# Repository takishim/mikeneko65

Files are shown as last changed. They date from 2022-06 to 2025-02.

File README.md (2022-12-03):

# Mikeneko65
(日本語版は[こちら](./README_jp.md))

A simple 65% keyboard for DIYers. This project was forked from [kkatano's Bakeneko65](https://github.com/kkatano/bakeneko-65).

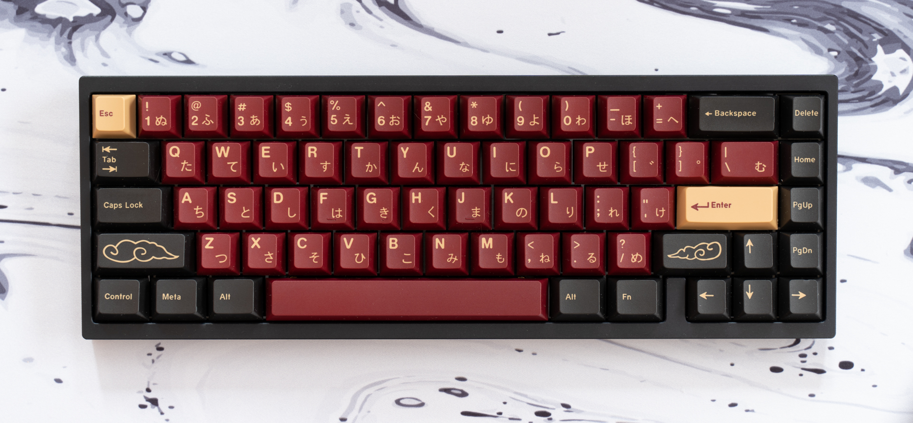
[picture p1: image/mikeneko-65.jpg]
Mikeneko65


-  [【極上の打鍵感】Mikeneko65 レビュー | Mikeneko65 : Custom Mechanical Keyboard Review](https://www.youtube.com/watch?v=eKG2YrfDjyA)

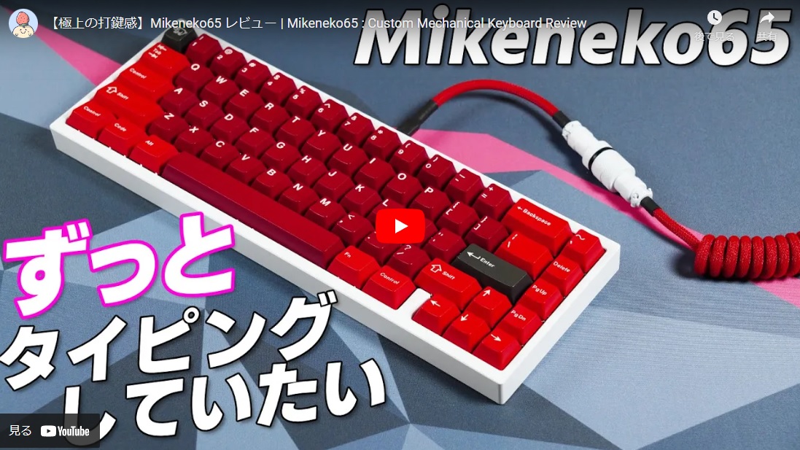
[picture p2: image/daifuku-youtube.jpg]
【極上の打鍵感】Mikeneko65 レビュー | Mikeneko65 : Custom Mechanical Keyboard Review (https://www.youtube.com/watch?v=eKG2YrfDjyA)


## Updates

### Differences between Bakeneko65 V3 and Mikeneko65

- Changed switch type from soldering to hotswap socket
- Supported for PCB screw-ins stabilizer
- Changed MCU to ATmega32U4-MU(R) to deal with MCU supply shortage
- Added pcb/case/sockeet/switch foam

## Features

- Single piece tray case
- O-ring gasket mount (Friction fit)
- Uses [Unified Daughterboard](https://github.com/ai03-2725/Unified-Daughterboard) and [Simplified Daughterboard](https://github.com/kb-elmo/simplified-daughterboard) as daughterboard
- Supports QMK firmware, VIA, Remap and Vial
- PCB designed with KiCAD 5.1.12

## Layout

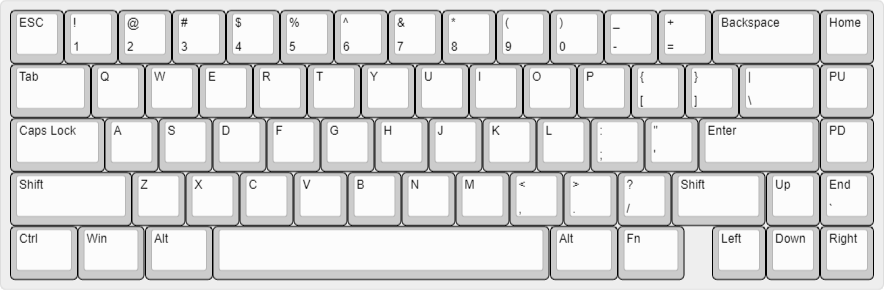
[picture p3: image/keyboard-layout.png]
Mikeneko65 layouts


## Buide guide

[Build Guide(English)](https://github.com/takishim/mikeneko65-docs/blob/master/BUILDGUIDE_en.md)

## Specs

- Dimensions: 315 x 110 x 30mm
- Front height: 18.5mm
- Home row height: 31mm(with GMK keycaps and bumpons)
- Typing angle: 6 degree
- Weight: 760g
- O-ring gasket: VMQ-30A AS568-263(softer) or VMQ-50A AS568-264(harder) is recommended

## Notes

- All files are to be used at your own risk

## Firmware & JSON definition file
- [Firmware(VIA Supported)](./mikeneko65_via.hex)
- [Firmware(VIA NOT Supported)](./mikeneko65_default.hex)
- [QMK Source Code](https://github.com/qmk/qmk_firmware/tree/master/keyboards/mikeneko65)
- [VIA Source Code](https://github.com/the-via/keyboards/tree/master/src/mikeneko65)
- [JSON file for VIA/Remap/Vial](./mikeneko65_via.json))
- [JOSN file for KeyboardLayoutEditor](./mikeneko65_kle.json))

You can download firmware and JSON files by right-clicking on the link and selecting "Save link as".  
These firmwares are built with QMK 0.17.9.

## Community

- Discord: [takishim's server](https://discord.gg/w4NRNrZkBp)
  - Have fun with community members
  - Talk about Mikeneko65 builds and mods, and share your works
  - You can also contact me from there

Please do not ask questions about Mikeneko65 on kkatano's discord server as it will be an inconvenience.

## Special thanks to

- **kkatano** Open-sourced Bakeneko65 and answered my questions in his community
- **desuchan** Allowed me to use the plate he designed
- People who supported the development of Mikeneko65

## Also I should mention
- Many keyboard community members for giving me advice and feedback, really thanks!

## Kit
Available at [Takishim Studio](https://takishim.com/).

## Photo Gallery
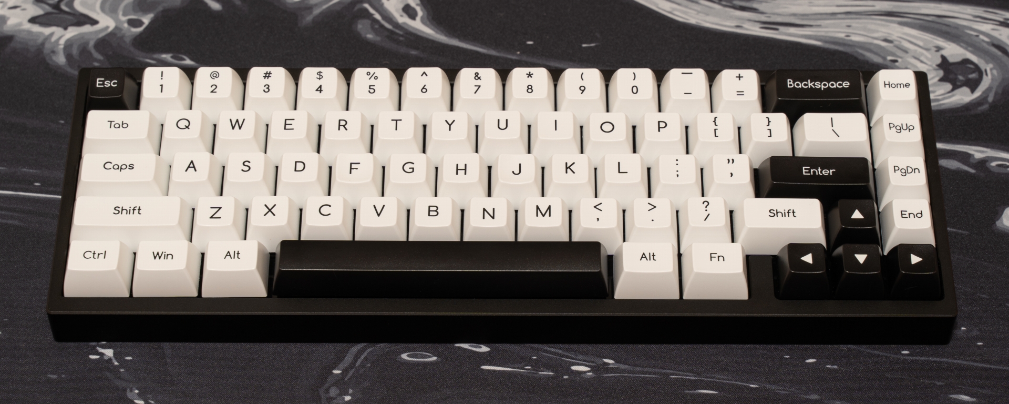
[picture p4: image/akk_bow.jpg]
akk_bow

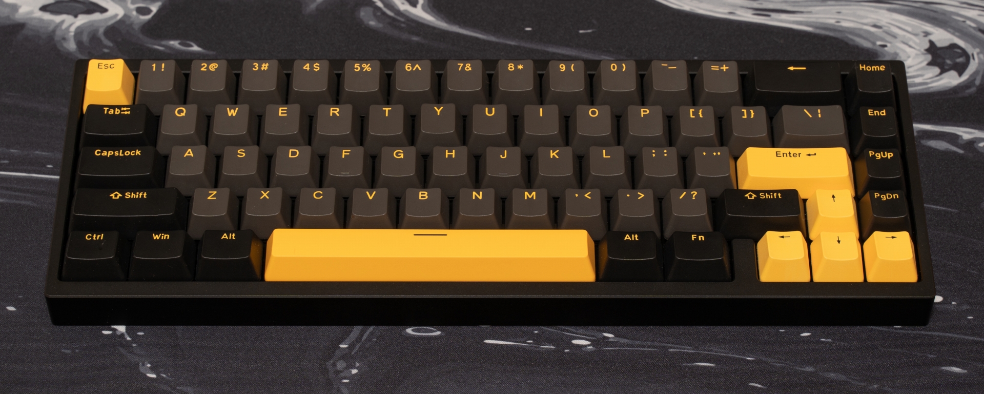
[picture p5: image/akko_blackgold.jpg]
akko_blackgold

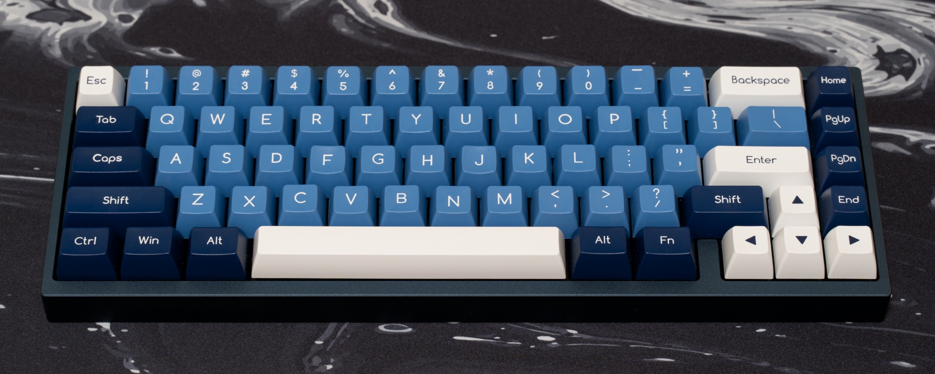
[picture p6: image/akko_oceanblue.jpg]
akko_oceanblue

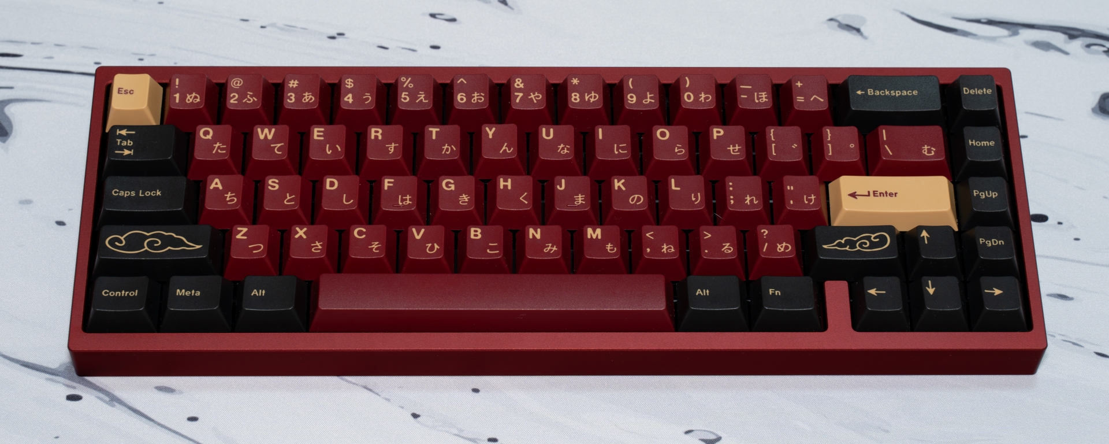
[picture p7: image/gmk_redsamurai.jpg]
gmk_redsamurai

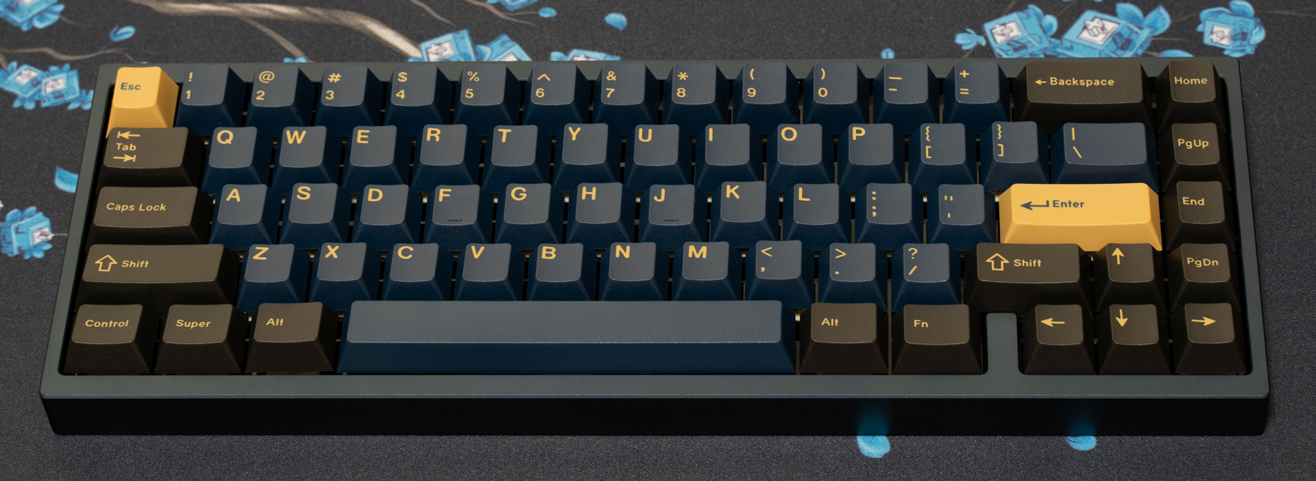
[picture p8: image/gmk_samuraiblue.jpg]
gmk_samuraiblue

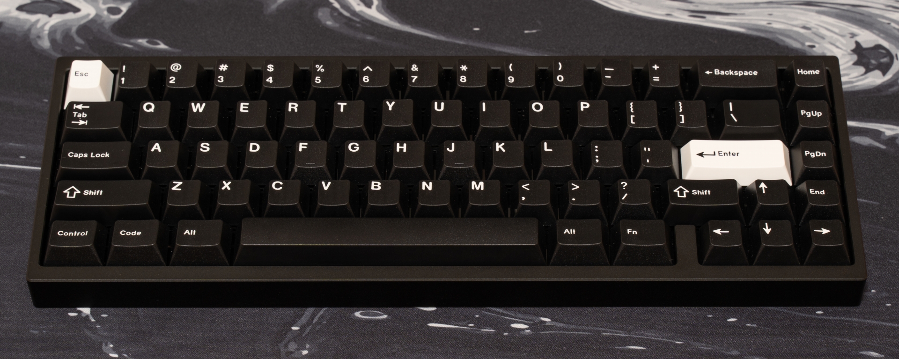
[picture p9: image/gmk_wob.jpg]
gmk_wob

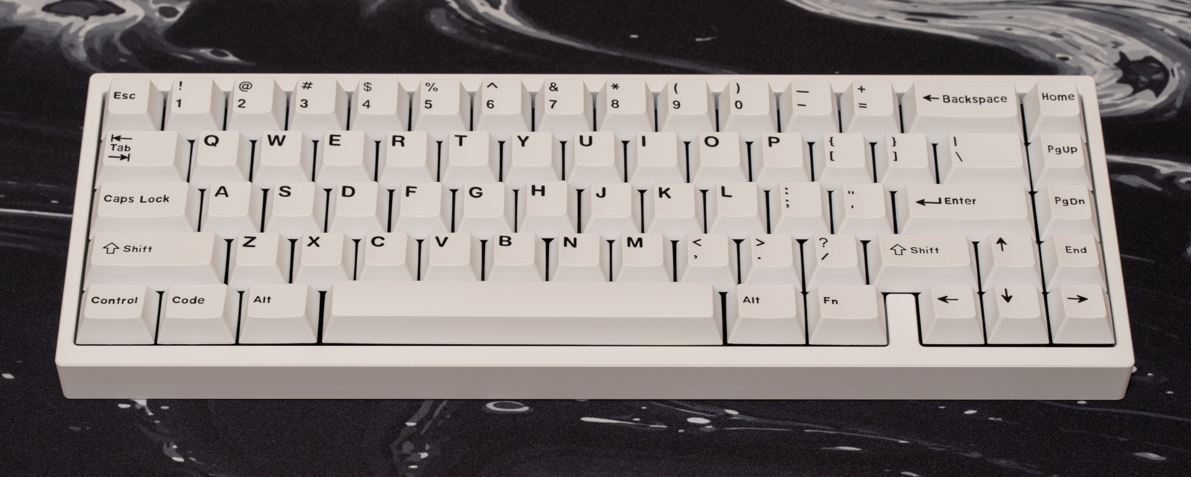
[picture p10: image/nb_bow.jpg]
nb_bow

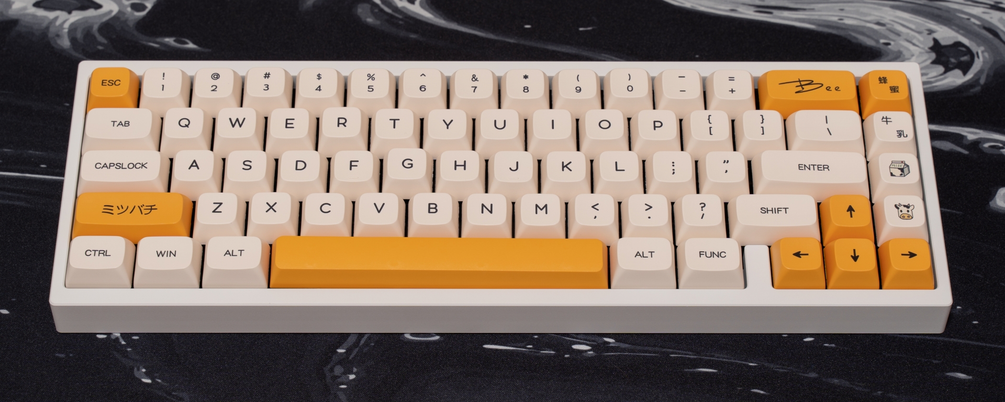
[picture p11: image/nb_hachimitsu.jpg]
nb_hachimitsu

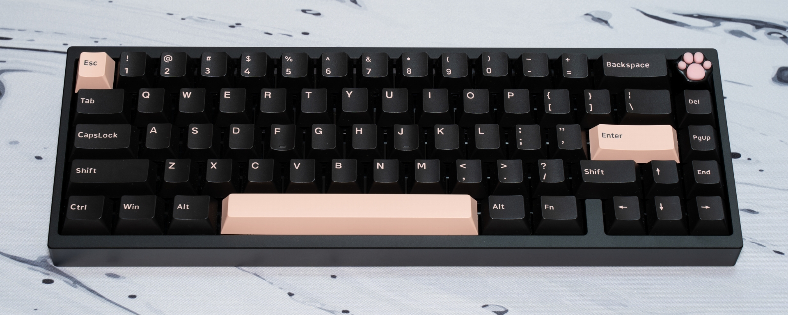
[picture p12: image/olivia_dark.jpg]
olivia_dark

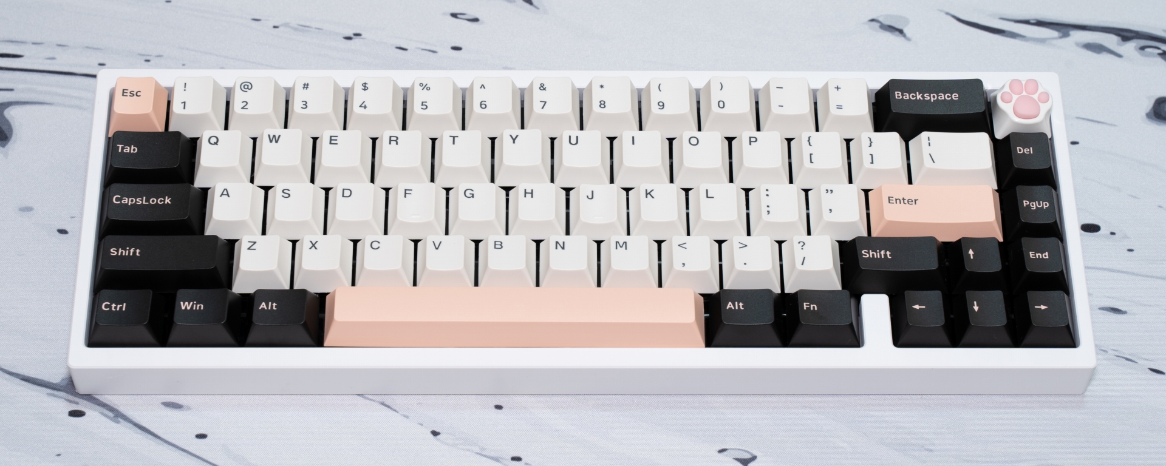
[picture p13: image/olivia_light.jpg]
olivia_light

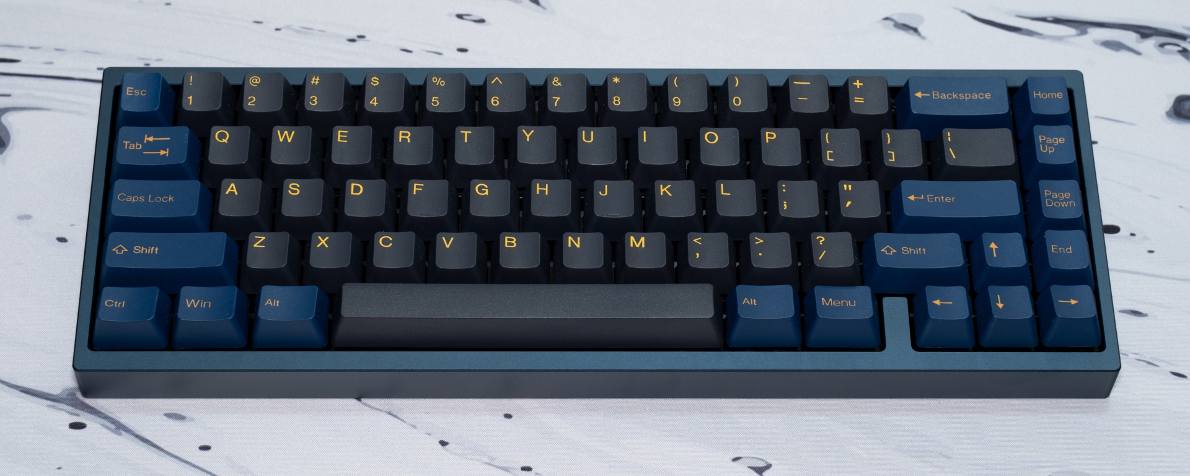
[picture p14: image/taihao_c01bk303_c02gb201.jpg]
taihao_c01bk303_c02gb201


## Reveiw Movies
[4K Mikeneko65](https://www.youtube.com/watch?v=AP2OyEw8YFc) by KS Japan

[Mikeneko65 with Gateron Oil King [Sound Test]](https://www.youtube.com/watch?v=dd4mWbpZy44) by Keyboard Test

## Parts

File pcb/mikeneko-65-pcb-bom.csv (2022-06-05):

Designator | Comment | Footprint | LCSC Part #
C1 C2 C3 | 0.1u | Capacitor_SMD:C_0805_2012Metric | C49678
C4 | 10u | Capacitor_SMD:C_0805_2012Metric | C15850
C5 C6 | 22p | Capacitor_SMD:C_0805_2012Metric | C1804
C7 | 1u | Capacitor_SMD:C_0805_2012Metric | C28323
D1 D2 D3 D4 D5 D6 D7 D8 D9 D10 D11 D12 D13 D14 D15 D16 D17 D18 D19 D20 D21 D22 D23 D24 D25 D26 D27 D28 D29 D30 D31 D32 D33 D34 D35 D36 D37 D38 D39 D40 D41 D42 D43 D44 D45 D46 D47 D48 D49 D50 D51 D52 D53 D54 D55 D56 D57 D58 D59 D60 D61 D62 D63 D64 D65 D66 D67 | 1N4148 | Diode_SMD:D_SOD-123 | C81598
F1 | 500mA | Fuse:Fuse_1206_3216Metric | C70076
J1 | JST SH 4-pin | Connector_JST:JST_SH_SM04B-SRSS-TB_1x04-1MP_P1.00mm_Horizontal | C145956
MX1 MX2 MX3 MX4 MX5 MX6 MX7 MX8 MX9 MX10 MX11 MX12 MX13 MX15 MX17 MX18 MX19 MX20 MX21 MX22 MX23 MX24 MX25 MX26 MX27 MX28 MX30 MX32 MX33 MX34 MX35 MX36 MX37 MX38 MX39 MX40 MX41 MX42 MX44 MX46 MX47 MX48 MX49 MX50 MX51 MX52 MX53 MX54 MX55 MX57 MX58 MX65 MX66 MX67 | 1u | MX_Only:MXOnly-1U-Hotswap | C2803348
MX14 | 2u | MX_Only:MXOnly-2U-Hotswap | C2803348
MX16 MX29 | 1.5u | MX_Only:MXOnly-1.5U-Hotswap | C2803348
MX31 MX56 | 1.75u | MX_Only:MXOnly-1.75U-Hotswap | C2803348
MX43 MX45 | 2.25u | MX_Only:MXOnly-2.25U-Hotswap | C2803348
MX59 MX60 MX61 MX63 MX64 | 1.25u | MX_Only:MXOnly-1.25U-Hotswap | C2803348
MX62 | 6.25u | MX_Only:MXOnly-6.25U-Hotswap-ReversedStabilizers | C2803348
R1 R4 | 10k | Resistor_SMD:R_0805_2012Metric | C17414
R2 R3 | 22 | Resistor_SMD:R_0805_2012Metric | C17561
SW1 | Reset | Button_Switch_SMD:SW_SPST_TL3342 | C318884
U1 | SRV05-4 | Package_TO_SOT_SMD:SOT-23-6 | C85364
U2 | ATmega32U4-MUR | Package_DFN_QFN:QFN-44-1EP_7x7mm_P0.5mm_EP5.2x5.2mm | C45874
Y1 | 16MHz | Crystal:Crystal_SMD_3225-4Pin_3.2x2.5mm | C13738

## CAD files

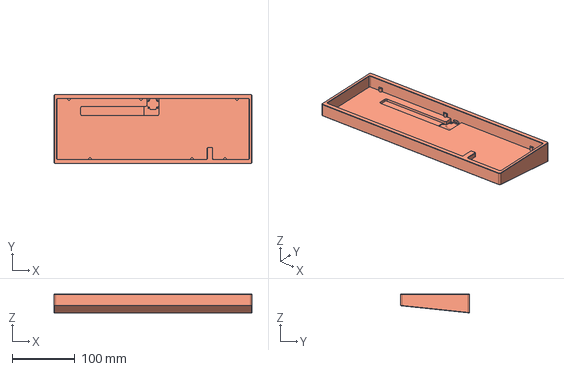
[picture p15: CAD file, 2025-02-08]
case/mikeneko65-simple-case.step
314.8 x 110.2 x 30.0 mm

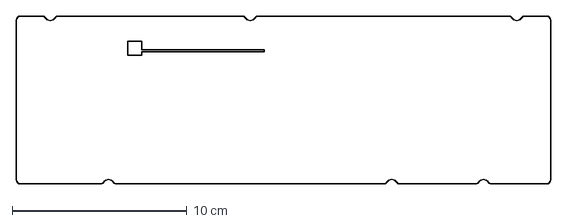
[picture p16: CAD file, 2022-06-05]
foam/mikeneko-65-case-foam.dxf
30.5 x 9.58 cm

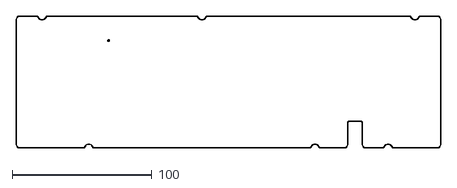
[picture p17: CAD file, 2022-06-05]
pcb/pcb-outline.dxf
303.8 x 94.2

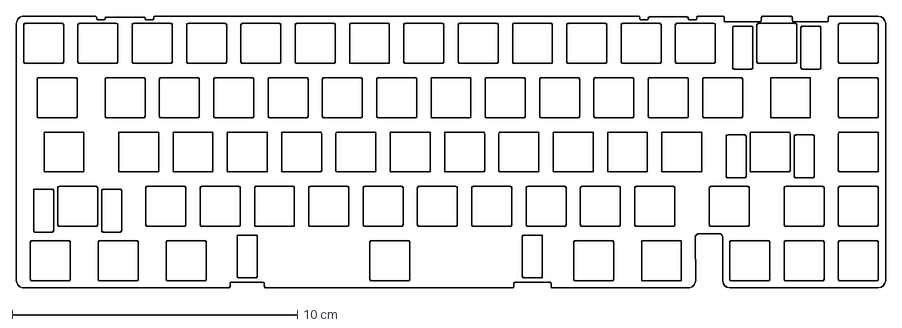
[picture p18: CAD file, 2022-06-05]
plate/mikeneko-65-plate.dxf
30.5 x 9.53 cm

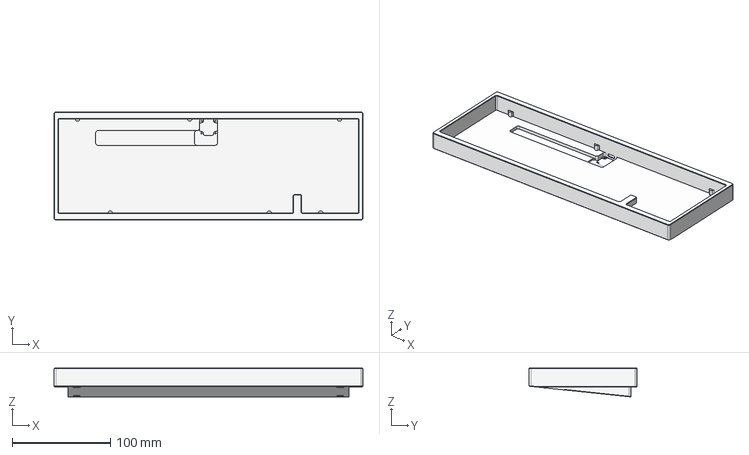
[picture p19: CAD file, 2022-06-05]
case/mikeneko-65-case.step
314.8 x 110.2 x 29.4 mm

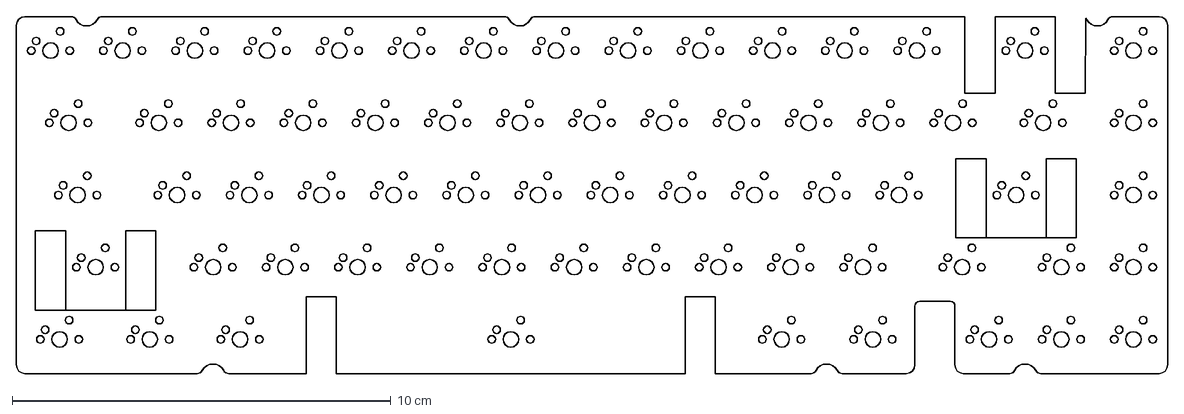
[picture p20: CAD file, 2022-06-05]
foam/mikeneko-65-switch-foam.dxf
30.4 x 9.42 cm

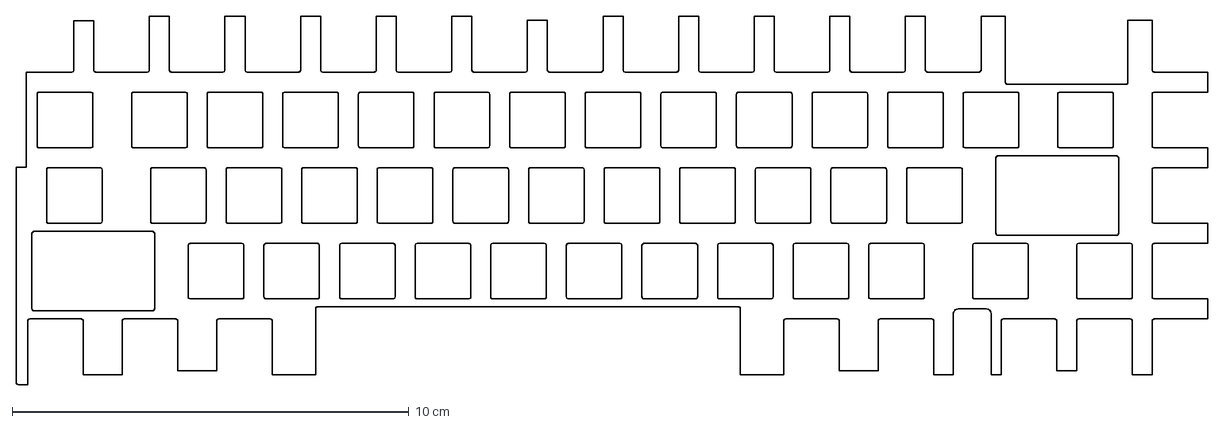
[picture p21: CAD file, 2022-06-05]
foam/mikeneko-65-pcb-foam.dxf
30.0 x 9.27 cm

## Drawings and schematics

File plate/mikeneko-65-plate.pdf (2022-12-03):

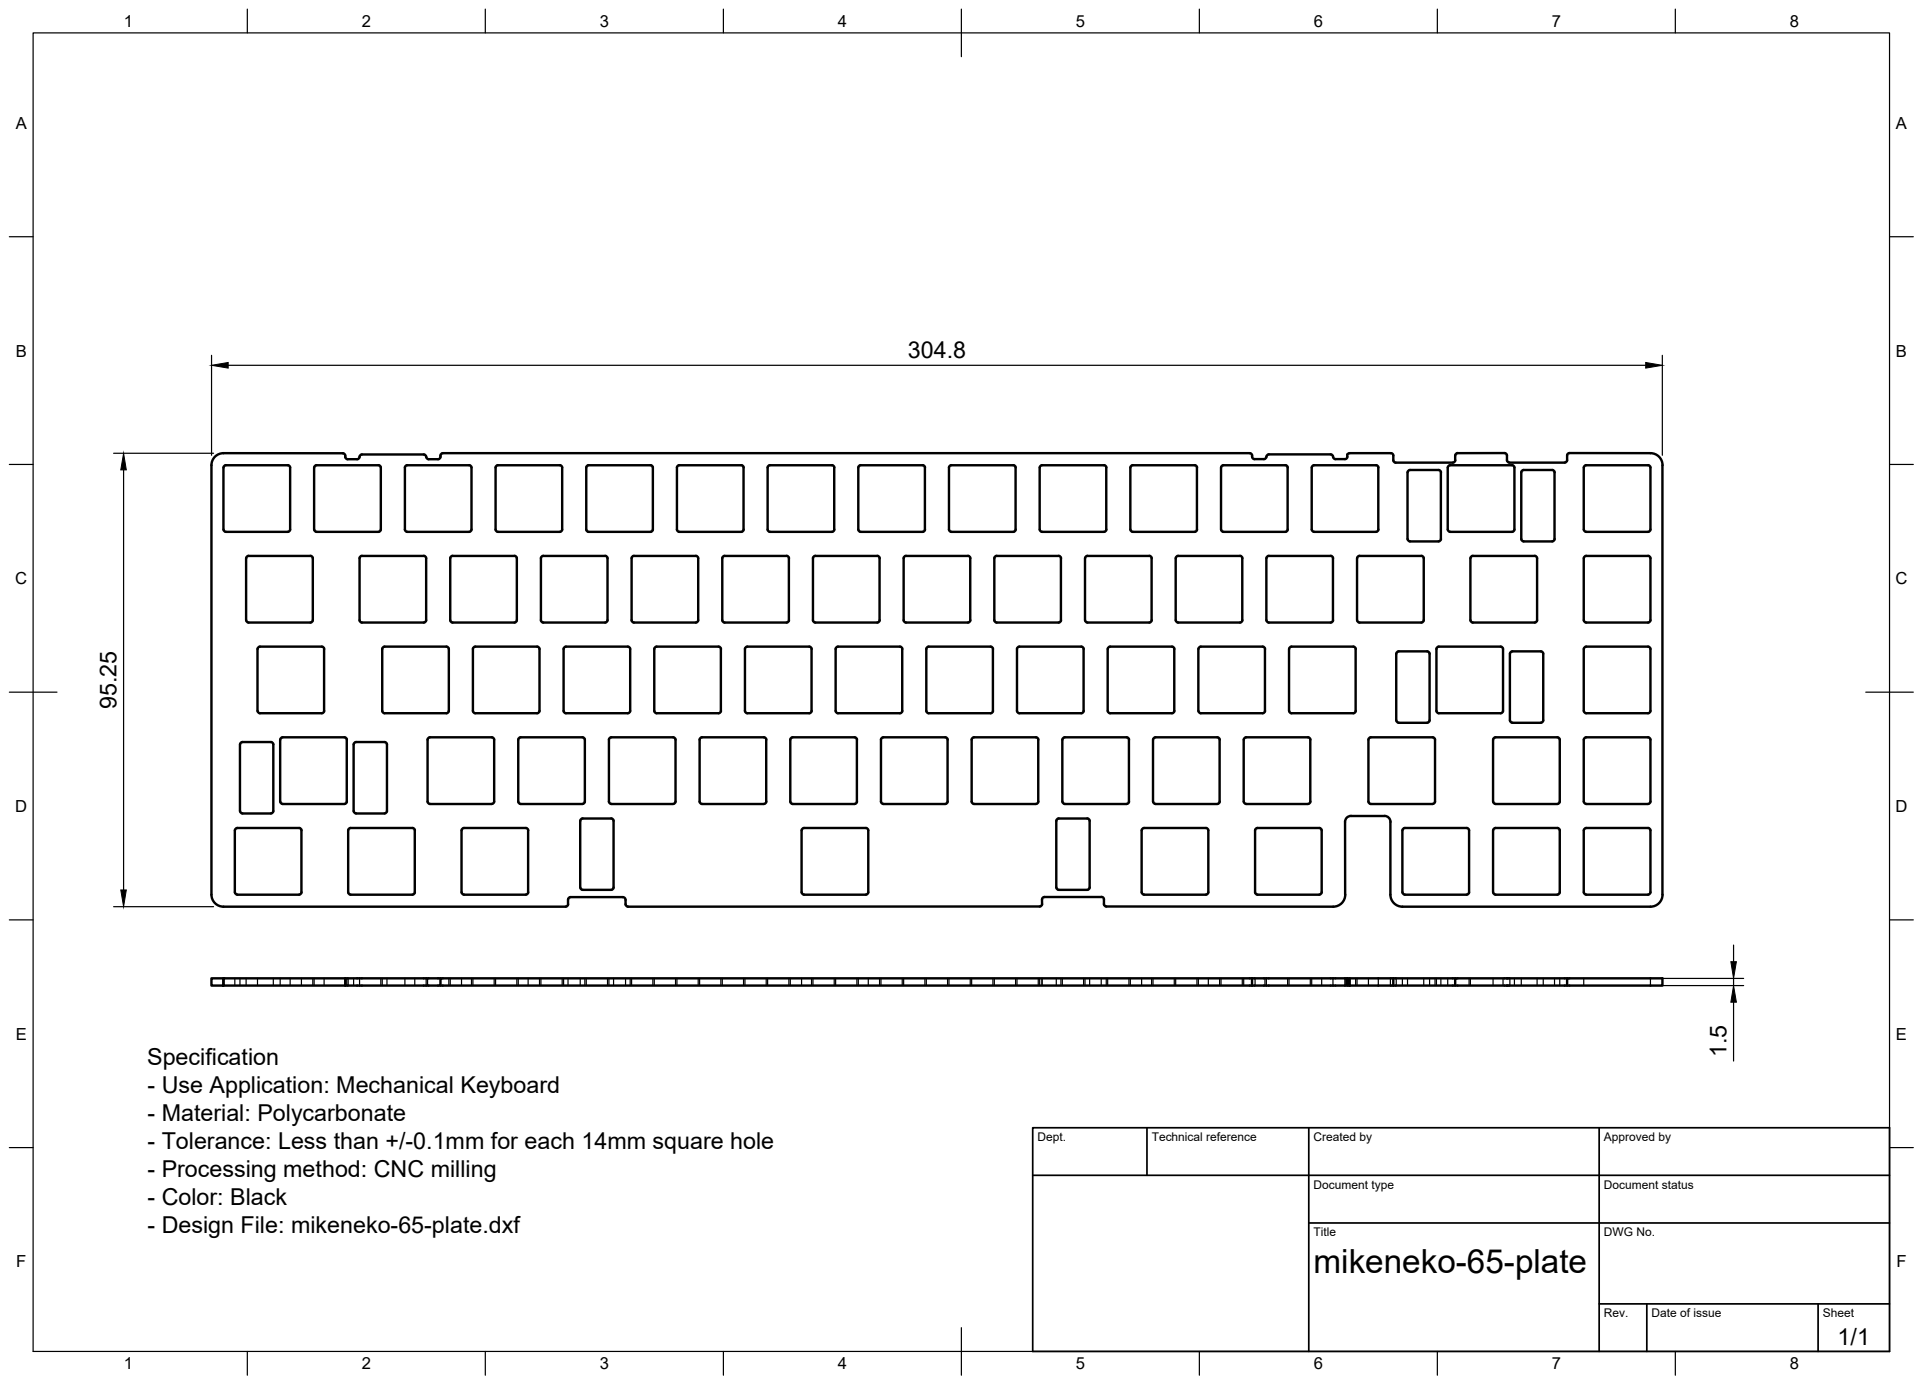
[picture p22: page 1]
Title; DWG No.; Rev.; Date of issue; Sheet

Specification
- Use Application: Mechanical Keyboard
- Material: Polycarbonate
- Tolerance: Less than +/-0.1mm for each 14mm square hole
- Processing method: CNC milling
- Color: Black
- Design File: mikeneko-65-plate.dxf

Dept. | Technical reference | Created by | Approved by

Document type | Document status

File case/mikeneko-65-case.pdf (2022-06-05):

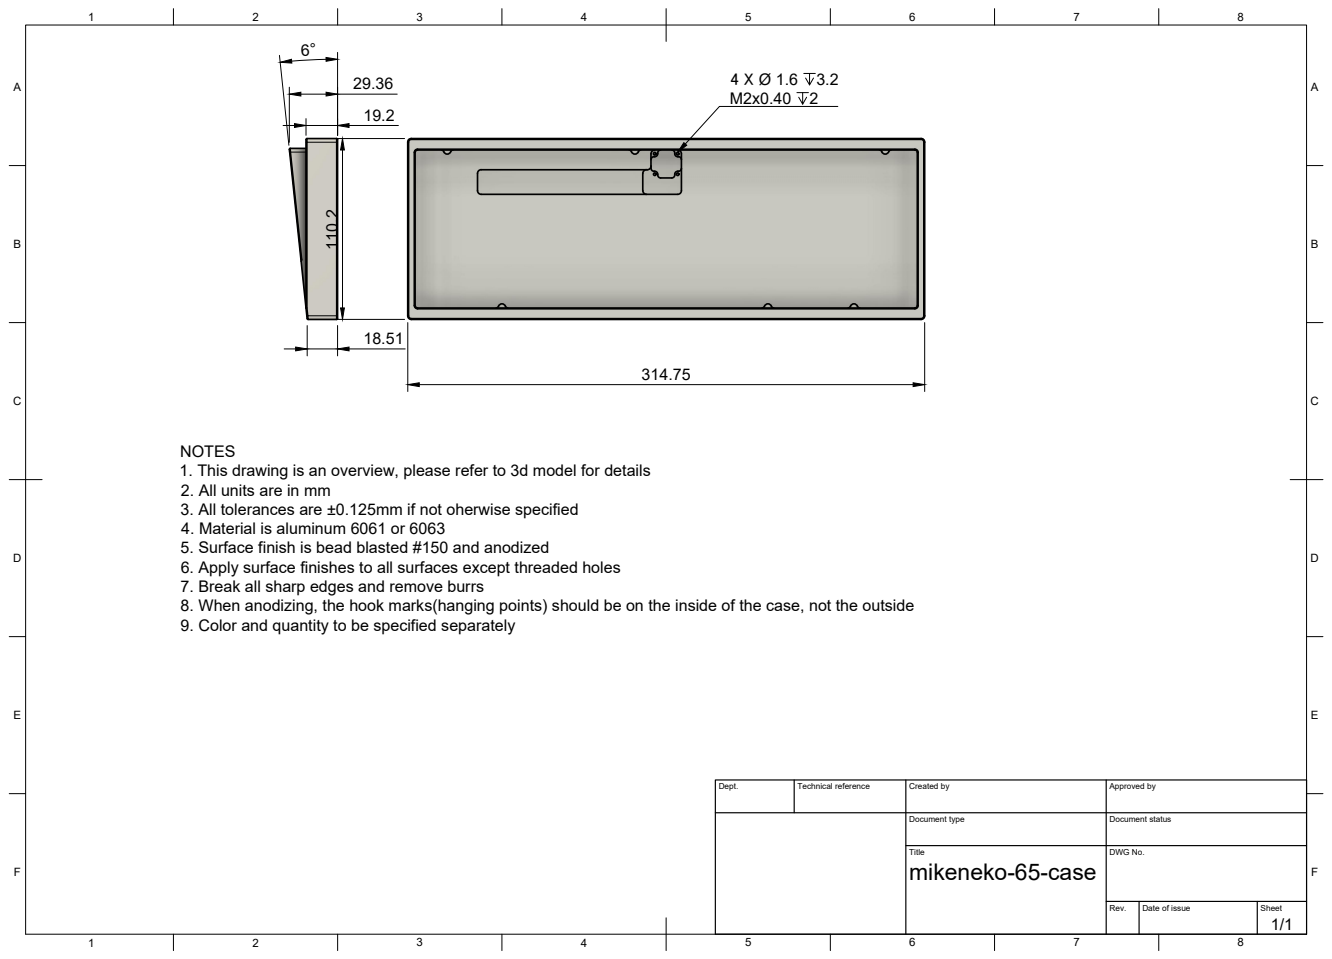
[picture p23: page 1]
Title; DWG No.; Rev.; Date of issue; Sheet

NOTES
1. This drawing is an overview, please refer to 3d model for details
2. All units are in mm
3. All tolerances are ±0.125mm if not oherwise specified
4. Material is aluminum 6061 or 6063
5. Surface finish is bead blasted #150 and anodized
6. Apply surface finishes to all surfaces except threaded holes
7. Break all sharp edges and remove burrs
8. When anodizing, the hook marks(hanging points) should be on the inside of the case, not the outside
9. Color and quantity to be specified separately

Dept. | Technical reference | Created by | Approved by

Document type | Document status

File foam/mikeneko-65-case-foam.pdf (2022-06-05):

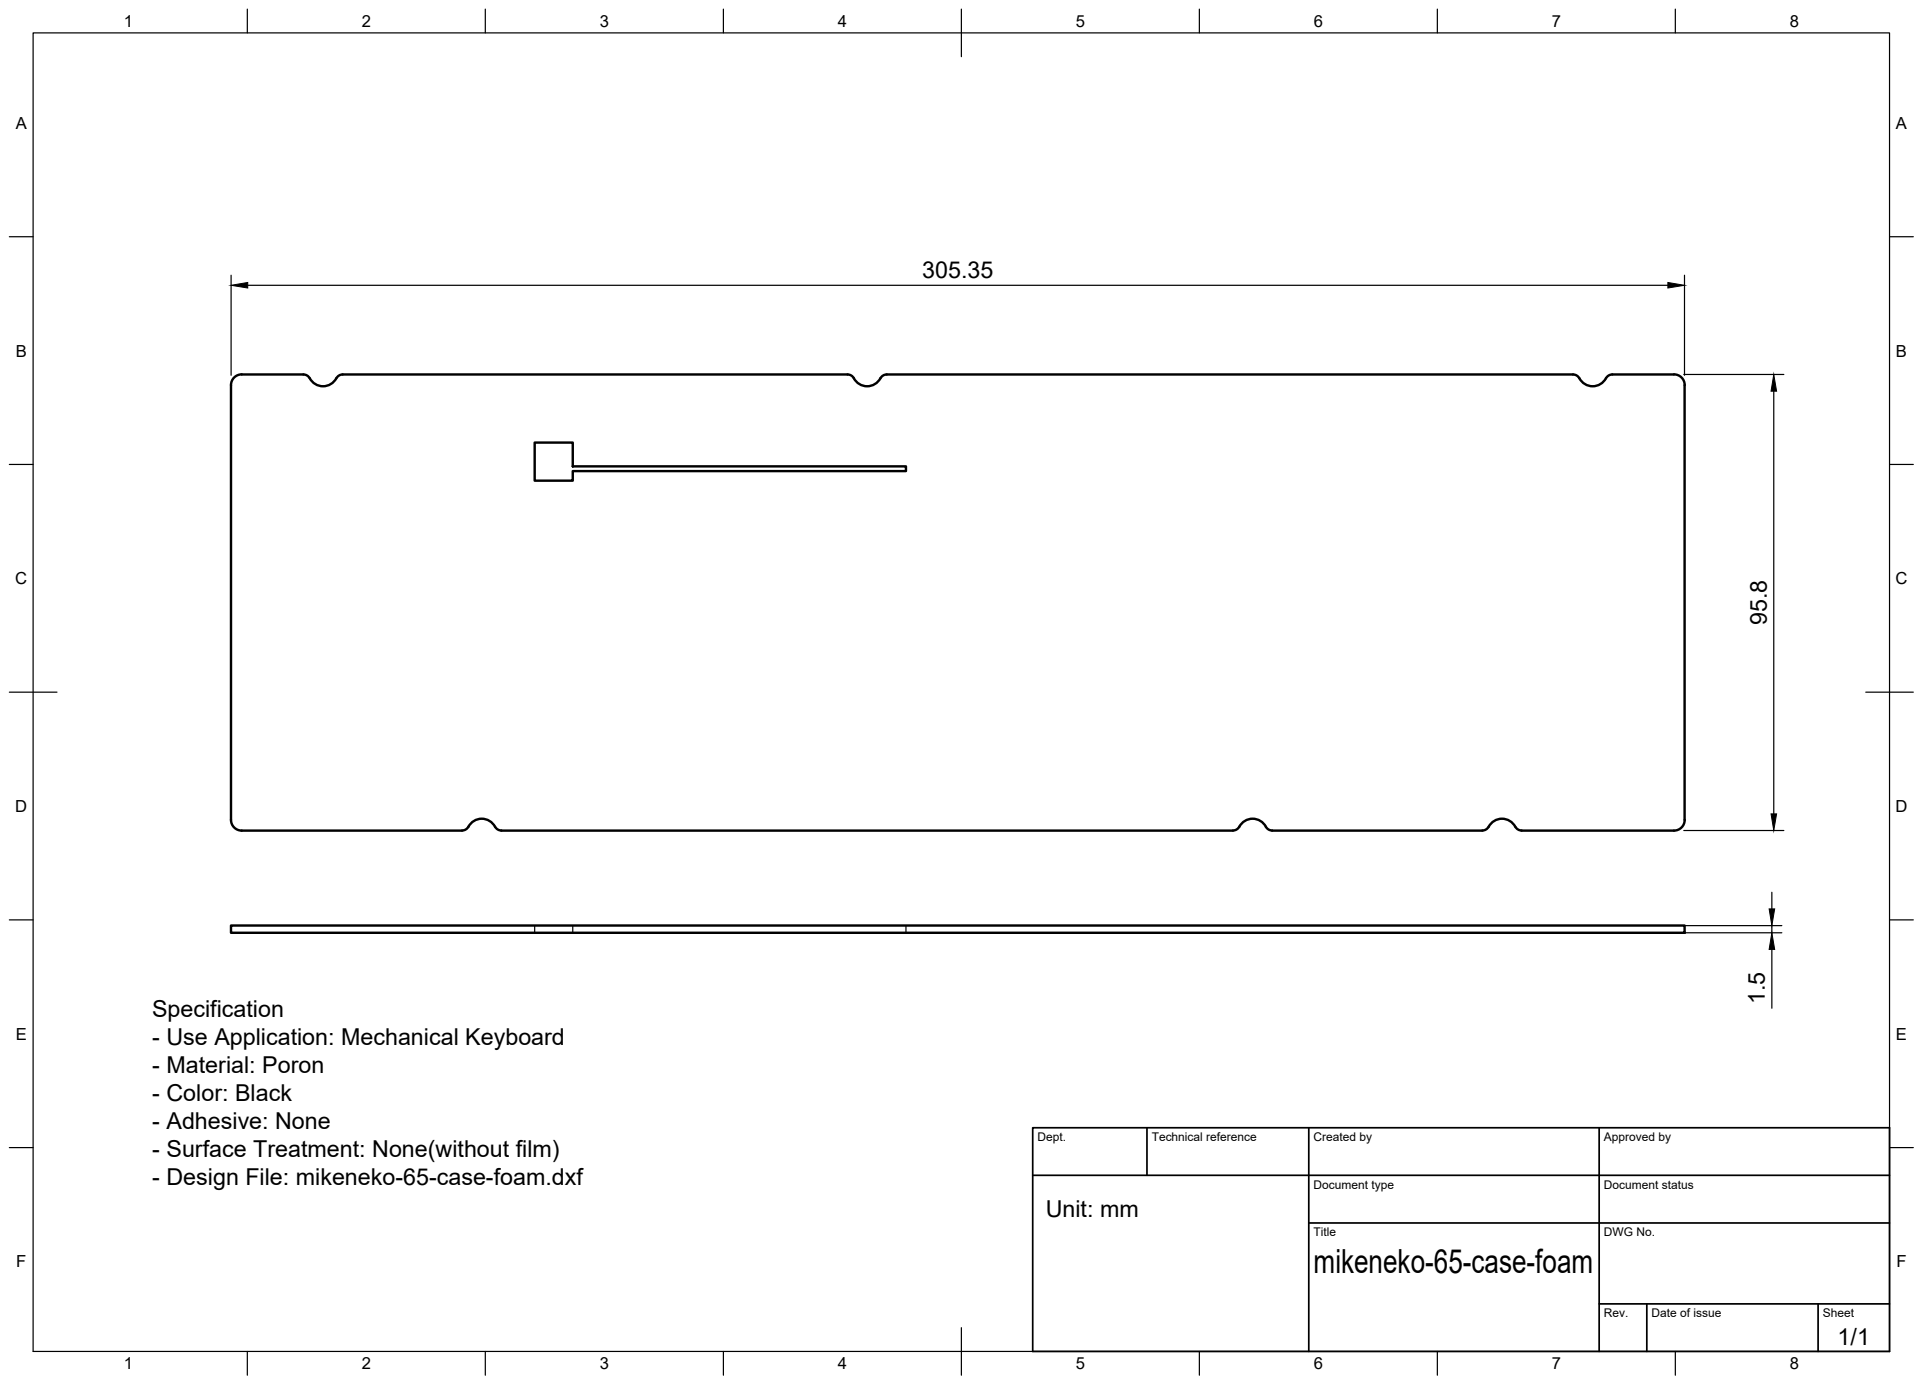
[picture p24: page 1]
Title; DWG No.; Rev.; Date of issue; Sheet; Unit: mm

Specification
- Use Application: Mechanical Keyboard
- Material: Poron
- Color: Black
- Adhesive: None
- Surface Treatment: None(without film)
- Design File: mikeneko-65-case-foam.dxf

Dept. | Technical reference | Created by | Approved by

Document type | Document status

mikeneko-65-case-foam

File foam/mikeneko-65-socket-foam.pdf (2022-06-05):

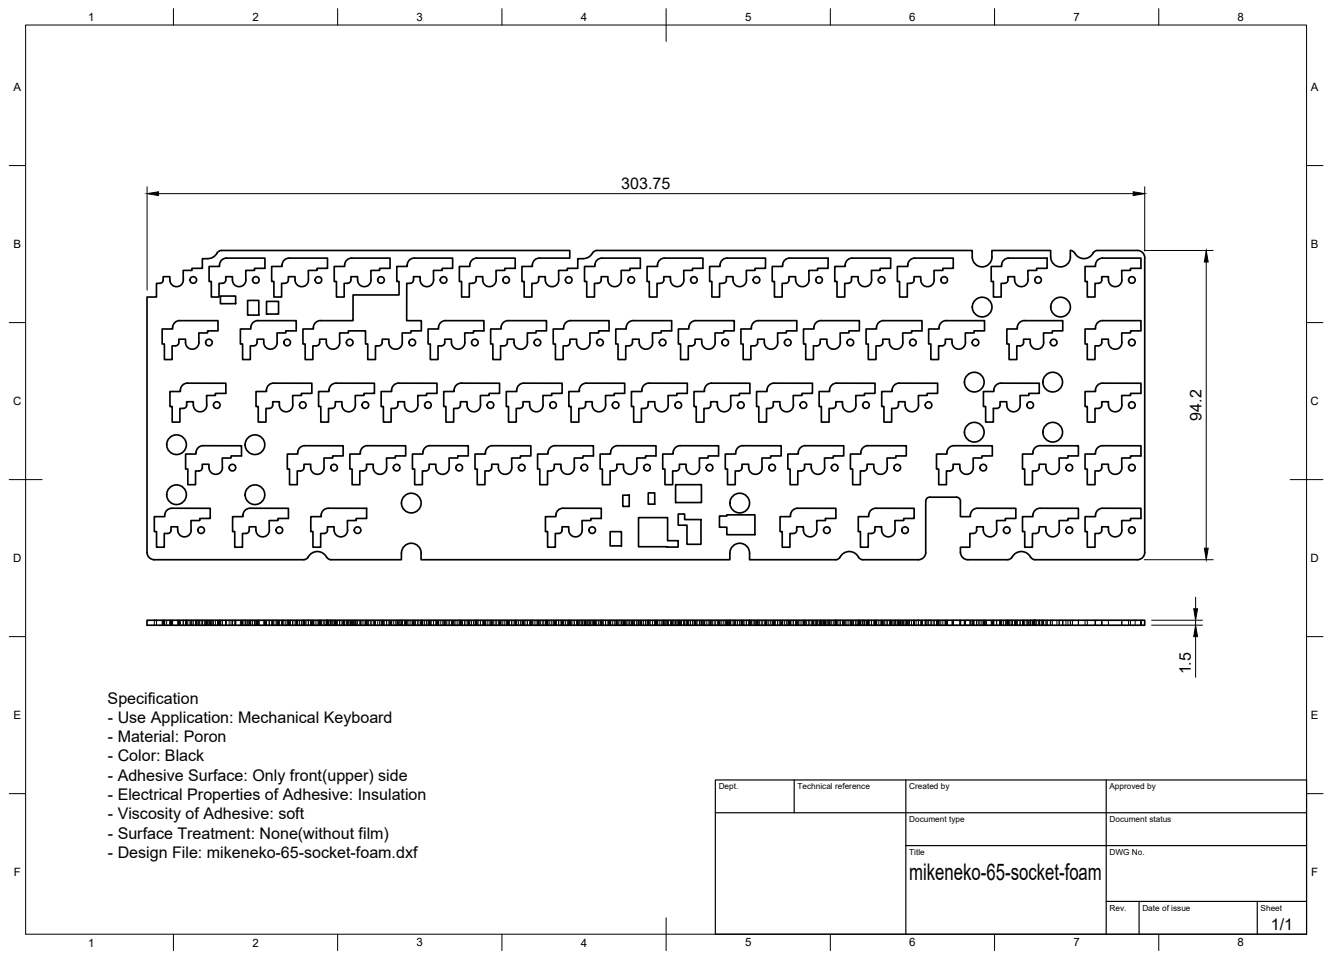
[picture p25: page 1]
Title; DWG No.; Rev.; Date of issue; Sheet

Specification
- Use Application: Mechanical Keyboard
- Material: Poron
- Color: Black
- Adhesive Surface: Only front(upper) side
- Electrical Properties of Adhesive: Insulation
- Viscosity of Adhesive: soft
- Surface Treatment: None(without film)
- Design File: mikeneko-65-socket-foam.dxf

Dept. | Technical reference | Created by | Approved by

Document type | Document status

mikeneko-65-socket-foam

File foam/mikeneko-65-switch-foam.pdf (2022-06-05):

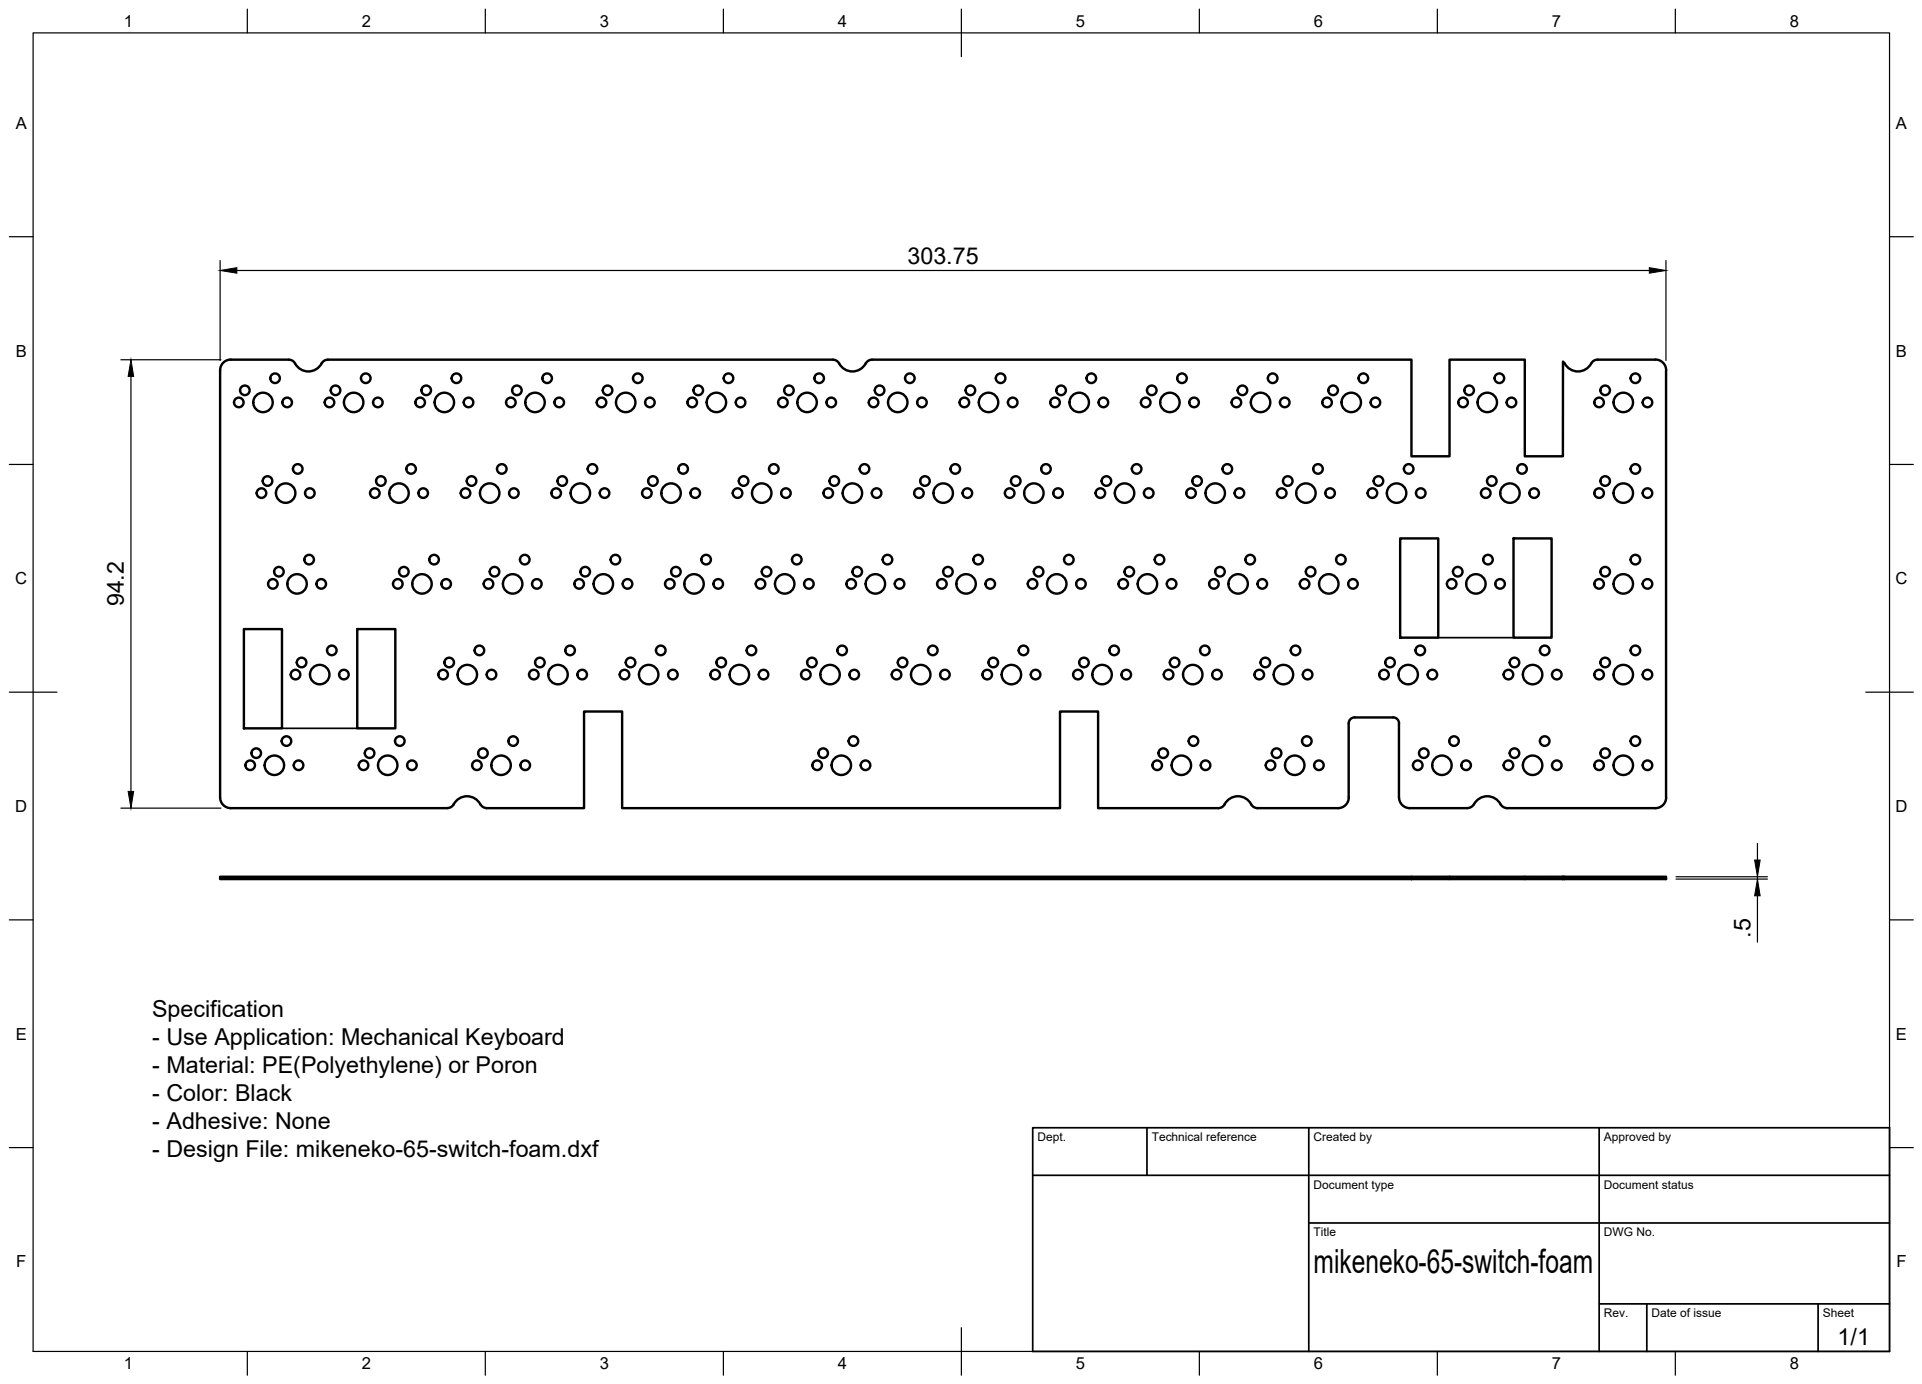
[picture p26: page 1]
Title; DWG No.; Rev.; Date of issue; Sheet

Specification
- Use Application: Mechanical Keyboard
- Material: PE(Polyethylene) or Poron
- Color: Black
- Adhesive: None
- Design File: mikeneko-65-switch-foam.dxf

Dept. | Technical reference | Created by | Approved by

Document type | Document status

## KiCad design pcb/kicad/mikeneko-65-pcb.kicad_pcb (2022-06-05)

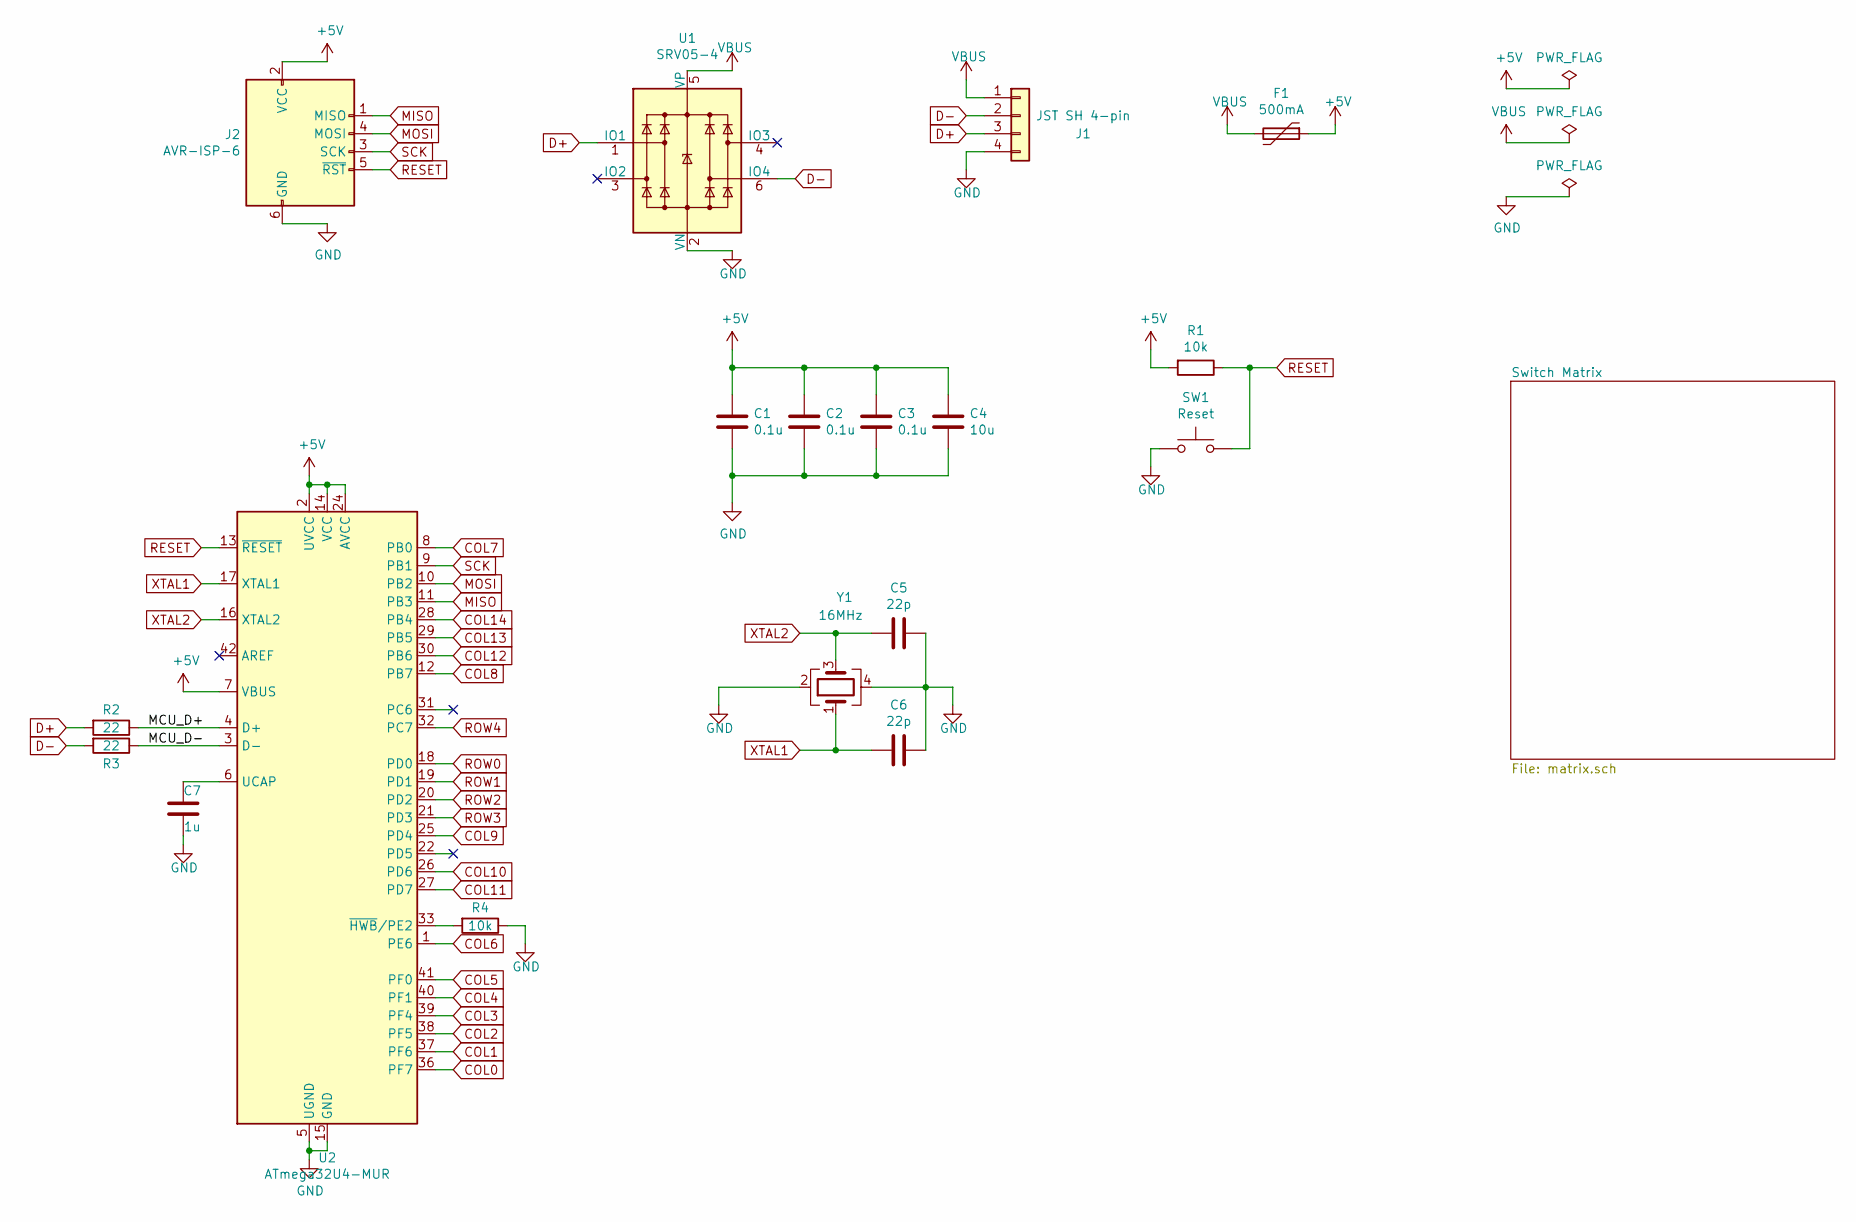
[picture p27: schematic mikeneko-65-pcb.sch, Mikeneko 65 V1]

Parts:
C1, C2, C3: 0.1u; C_0805_2012Metric; LCSC Part # C49678
C4: 10u; C_0805_2012Metric; LCSC Part # C15850
C5, C6: 22p; C_0805_2012Metric; LCSC Part # C1804
C7: 1u; C_0805_2012Metric; LCSC Part # C28323
F1: 500mA; Fuse_1206_3216Metric; LCSC Part # C70076
J1: JST SH 4-pin; JST_SH_SM04B-SRSS-TB_1x04-1MP_P1.00mm_Horizontal; LCSC Part # C145956
J2: AVR-ISP-6; ISP
R1, R4: 10k; R_0805_2012Metric; LCSC Part # C17414
R2, R3: 22; R_0805_2012Metric; LCSC Part # C17561
SW1: Reset; SW_SPST_TL3342; LCSC Part # C318884
U1: SRV05-4; SOT-23-6; LCSC Part # C85364
U2: ATmega32U4-MUR; QFN-44-1EP_7x7mm_P0.5mm_EP5.2x5.2mm; LCSC Part # C45874
Y1: 16MHz; Crystal_SMD_3225-4Pin_3.2x2.5mm; LCSC Part # C13738

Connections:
+5V: C1.1, C2.1, C3.1, C4.1, F1.1, J2.2 (VCC), R1.2, U2.2 (UVCC), U2.7 (VBUS), U2.14 (VCC), U2.24 (AVCC), U2.34 (VCC), U2.44 (AVCC)
/MCU_D+: R2.1, U2.4 (D+)
/MCU_D-: R3.1, U2.3 (D-)
COL0: U2.36 (PF7); also elsewhere on the board
COL1: U2.37 (PF6); also elsewhere on the board
COL2: U2.38 (PF5); also elsewhere on the board
COL3: U2.39 (PF4); also elsewhere on the board
COL4: U2.40 (PF1); also elsewhere on the board
COL5: U2.41 (PF0); also elsewhere on the board
COL6: U2.1 (PE6); also elsewhere on the board
COL7: U2.8 (PB0); also elsewhere on the board
COL8: U2.12 (PB7); also elsewhere on the board
COL9: U2.25 (PD4); also elsewhere on the board
COL10: U2.26 (PD6); also elsewhere on the board
COL11: U2.27 (PD7); also elsewhere on the board
COL12: U2.30 (PB6); also elsewhere on the board
COL13: U2.29 (PB5); also elsewhere on the board
COL14: U2.28 (PB4); also elsewhere on the board
D+: J1.3, R2.2, U1.1 (IO1)
D-: J1.2, R3.2, U1.6 (IO4)
GND: C1.2, C2.2, C3.2, C4.2, C5.1, C6.1, C7.2, J1.4, J2.6 (GND), R4.1, SW1.1, U1.2 (VN), U2.5 (UGND), U2.15 (GND), U2.23 (GND), U2.35 (GND), U2.43 (GND), U2.45 (GND), Y1.2, Y1.4
MISO: J2.1 (MISO), U2.11 (PB3)
MOSI: J2.4 (MOSI), U2.10 (PB2)
unnamed: C7.1, U2.6 (UCAP)
unnamed: R4.2, U2.33 (~HWB~/PE2)
RESET: J2.5 (~RST), R1.1, SW1.2, U2.13 (~RESET)
ROW0: U2.18 (PD0); also elsewhere on the board
ROW1: U2.19 (PD1); also elsewhere on the board
ROW2: U2.20 (PD2); also elsewhere on the board
ROW3: U2.21 (PD3); also elsewhere on the board
ROW4: U2.32 (PC7); also elsewhere on the board
SCK: J2.3 (SCK), U2.9 (PB1)
VBUS: F1.2, J1.1, U1.5 (VP)
XTAL1: C6.2, U2.17 (XTAL1), Y1.1
XTAL2: C5.2, U2.16 (XTAL2), Y1.3

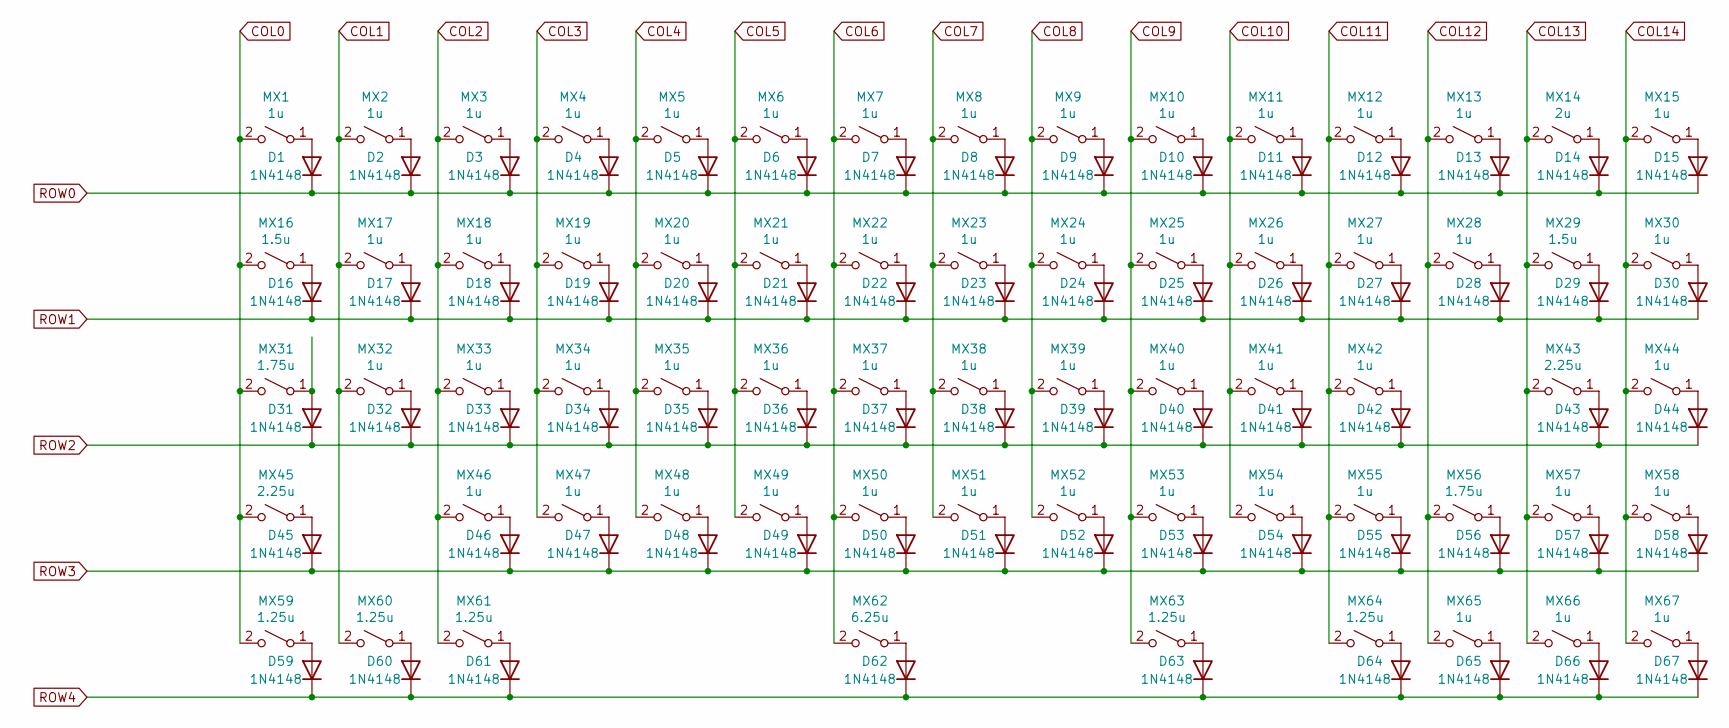
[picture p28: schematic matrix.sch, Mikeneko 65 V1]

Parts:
D1, D2, D3, D4, D5, D6, D7, D8, D9, D10, D11, D12, D13, D14, D15, D16, D17, D18, D19, D20, D21, D22, D23, D24, D25, D26, D27, D28, D29, D30, D31, D32, D33, D34, D35, D36, D37, D38, D39, D40, D41, D42, D43, D44, D45, D46, D47, D48, D49, D50, D51, D52, D53, D54, D55, D56, D57, D58, D59, D60, D61, D62, D63, D64, D65, D66, D67: 1N4148; D_SOD-123; LCSC Part # C81598
MX1, MX2, MX3, MX4, MX5, MX6, MX7, MX8, MX9, MX10, MX11, MX12, MX13, MX15, MX17, MX18, MX19, MX20, MX21, MX22, MX23, MX24, MX25, MX26, MX27, MX28, MX30, MX32, MX33, MX34, MX35, MX36, MX37, MX38, MX39, MX40, MX41, MX42, MX44, MX46, MX47, MX48, MX49, MX50, MX51, MX52, MX53, MX54, MX55, MX57, MX58, MX65, MX66, MX67: 1u; MXOnly-1U-Hotswap; LCSC Part # C2803348
MX14: 2u; MXOnly-2U-Hotswap; LCSC Part # C2803348
MX16, MX29: 1.5u; MXOnly-1.5U-Hotswap; LCSC Part # C2803348
MX31, MX56: 1.75u; MXOnly-1.75U-Hotswap; LCSC Part # C2803348
MX43, MX45: 2.25u; MXOnly-2.25U-Hotswap; LCSC Part # C2803348
MX59, MX60, MX61, MX63, MX64: 1.25u; MXOnly-1.25U-Hotswap; LCSC Part # C2803348
MX62: 6.25u; MXOnly-6.25U-Hotswap-ReversedStabilizers; LCSC Part # C2803348

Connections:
COL0: MX1.2 (B), MX16.2 (B), MX31.2 (B), MX45.2 (B), MX59.2 (B); also elsewhere on the board
COL1: MX2.2 (B), MX17.2 (B), MX32.2 (B), MX60.2 (B); also elsewhere on the board
COL2: MX3.2 (B), MX18.2 (B), MX33.2 (B), MX46.2 (B), MX61.2 (B); also elsewhere on the board
COL3: MX4.2 (B), MX19.2 (B), MX34.2 (B), MX47.2 (B); also elsewhere on the board
COL4: MX5.2 (B), MX20.2 (B), MX35.2 (B), MX48.2 (B); also elsewhere on the board
COL5: MX6.2 (B), MX21.2 (B), MX36.2 (B), MX49.2 (B); also elsewhere on the board
COL6: MX7.2 (B), MX22.2 (B), MX37.2 (B), MX50.2 (B), MX62.2 (B); also elsewhere on the board
COL7: MX8.2 (B), MX23.2 (B), MX38.2 (B), MX51.2 (B); also elsewhere on the board
COL8: MX9.2 (B), MX24.2 (B), MX39.2 (B), MX52.2 (B); also elsewhere on the board
COL9: MX10.2 (B), MX25.2 (B), MX40.2 (B), MX53.2 (B), MX63.2 (B); also elsewhere on the board
COL10: MX11.2 (B), MX26.2 (B), MX41.2 (B), MX54.2 (B); also elsewhere on the board
COL11: MX12.2 (B), MX27.2 (B), MX42.2 (B), MX55.2 (B), MX64.2 (B); also elsewhere on the board
COL12: MX13.2 (B), MX28.2 (B), MX56.2 (B), MX65.2 (B); also elsewhere on the board
COL13: MX14.2 (B), MX29.2 (B), MX43.2 (B), MX57.2 (B), MX66.2 (B); also elsewhere on the board
COL14: MX15.2 (B), MX30.2 (B), MX44.2 (B), MX58.2 (B), MX67.2 (B); also elsewhere on the board
unnamed: D1.2 (A), MX1.1 (A)
unnamed: D2.2 (A), MX2.1 (A)
unnamed: D3.2 (A), MX3.1 (A)
unnamed: D4.2 (A), MX4.1 (A)
unnamed: D5.2 (A), MX5.1 (A)
unnamed: D6.2 (A), MX6.1 (A)
unnamed: D7.2 (A), MX7.1 (A)
unnamed: D8.2 (A), MX8.1 (A)
unnamed: D9.2 (A), MX9.1 (A)
unnamed: D10.2 (A), MX10.1 (A)
unnamed: D11.2 (A), MX11.1 (A)
unnamed: D12.2 (A), MX12.1 (A)
unnamed: D13.2 (A), MX13.1 (A)
unnamed: D14.2 (A), MX14.1 (A)
unnamed: D15.2 (A), MX15.1 (A)
unnamed: D16.2 (A), MX16.1 (A)
unnamed: D17.2 (A), MX17.1 (A)
unnamed: D18.2 (A), MX18.1 (A)
unnamed: D19.2 (A), MX19.1 (A)
unnamed: D20.2 (A), MX20.1 (A)
unnamed: D21.2 (A), MX21.1 (A)
unnamed: D22.2 (A), MX22.1 (A)
unnamed: D23.2 (A), MX23.1 (A)
unnamed: D24.2 (A), MX24.1 (A)
unnamed: D25.2 (A), MX25.1 (A)
unnamed: D26.2 (A), MX26.1 (A)
unnamed: D27.2 (A), MX27.1 (A)
unnamed: D28.2 (A), MX28.1 (A)
unnamed: D29.2 (A), MX29.1 (A)
unnamed: D30.2 (A), MX30.1 (A)
unnamed: D31.2 (A), MX31.1 (A)
unnamed: D32.2 (A), MX32.1 (A)
unnamed: D33.2 (A), MX33.1 (A)
unnamed: D34.2 (A), MX34.1 (A)
unnamed: D35.2 (A), MX35.1 (A)
unnamed: D36.2 (A), MX36.1 (A)
unnamed: D37.2 (A), MX37.1 (A)
unnamed: D38.2 (A), MX38.1 (A)
unnamed: D39.2 (A), MX39.1 (A)
unnamed: D40.2 (A), MX40.1 (A)
unnamed: D41.2 (A), MX41.1 (A)
unnamed: D42.2 (A), MX42.1 (A)
unnamed: D43.2 (A), MX43.1 (A)
unnamed: D44.2 (A), MX44.1 (A)
unnamed: D45.2 (A), MX45.1 (A)
unnamed: D46.2 (A), MX46.1 (A)
unnamed: D47.2 (A), MX47.1 (A)
unnamed: D48.2 (A), MX48.1 (A)
unnamed: D49.2 (A), MX49.1 (A)
unnamed: D50.2 (A), MX50.1 (A)
unnamed: D51.2 (A), MX51.1 (A)
unnamed: D52.2 (A), MX52.1 (A)
unnamed: D53.2 (A), MX53.1 (A)
unnamed: D54.2 (A), MX54.1 (A)
unnamed: D55.2 (A), MX55.1 (A)
unnamed: D56.2 (A), MX56.1 (A)
unnamed: D57.2 (A), MX57.1 (A)
unnamed: D58.2 (A), MX58.1 (A)
unnamed: D59.2 (A), MX59.1 (A)
unnamed: D60.2 (A), MX60.1 (A)
unnamed: D61.2 (A), MX61.1 (A)
unnamed: D62.2 (A), MX62.1 (A)
unnamed: D63.2 (A), MX63.1 (A)
unnamed: D64.2 (A), MX64.1 (A)
unnamed: D65.2 (A), MX65.1 (A)
unnamed: D66.2 (A), MX66.1 (A)
unnamed: D67.2 (A), MX67.1 (A)
ROW0: D1.1 (K), D2.1 (K), D3.1 (K), D4.1 (K), D5.1 (K), D6.1 (K), D7.1 (K), D8.1 (K), D9.1 (K), D10.1 (K), D11.1 (K), D12.1 (K), D13.1 (K), D14.1 (K), D15.1 (K); also elsewhere on the board
ROW1: D16.1 (K), D17.1 (K), D18.1 (K), D19.1 (K), D20.1 (K), D21.1 (K), D22.1 (K), D23.1 (K), D24.1 (K), D25.1 (K), D26.1 (K), D27.1 (K), D28.1 (K), D29.1 (K), D30.1 (K); also elsewhere on the board
ROW2: D31.1 (K), D32.1 (K), D33.1 (K), D34.1 (K), D35.1 (K), D36.1 (K), D37.1 (K), D38.1 (K), D39.1 (K), D40.1 (K), D41.1 (K), D42.1 (K), D43.1 (K), D44.1 (K); also elsewhere on the board
ROW3: D45.1 (K), D46.1 (K), D47.1 (K), D48.1 (K), D49.1 (K), D50.1 (K), D51.1 (K), D52.1 (K), D53.1 (K), D54.1 (K), D55.1 (K), D56.1 (K), D57.1 (K), D58.1 (K); also elsewhere on the board
ROW4: D59.1 (K), D60.1 (K), D61.1 (K), D62.1 (K), D63.1 (K), D64.1 (K), D65.1 (K), D66.1 (K), D67.1 (K); also elsewhere on the board

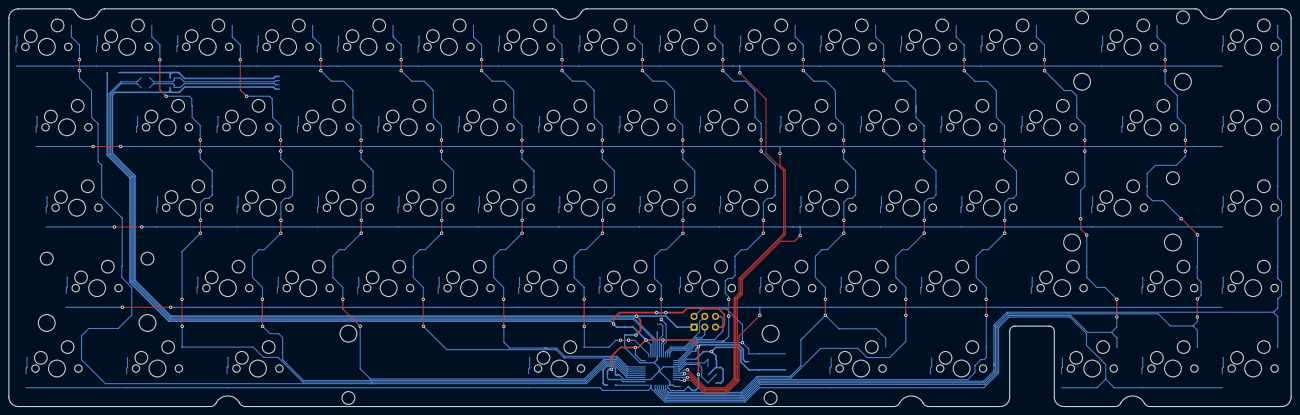
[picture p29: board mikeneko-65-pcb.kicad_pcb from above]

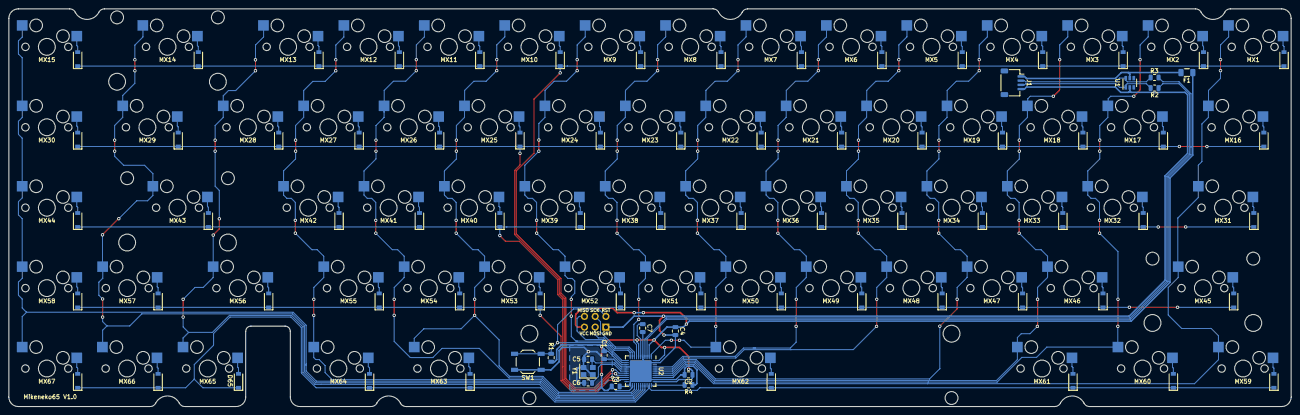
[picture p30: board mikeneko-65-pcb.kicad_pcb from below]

Board: 2 copper layers, 303.8 x 94.2 mm, 152 parts (84 on the bottom side), 102 nets.

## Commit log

2022-07-06 QMKとVIAのディレクトリを削除。 ファームウェアとJSON定義ファイルを整理&リポジトリの直下に移動。 READMEの上の修正を反映。
2022-07-06 直近の変更の修正。
2022-07-06 pcbディレクトリの下にkicadディレクトリを作ってkicad関連ファイルをそこに移動。
    [matrix.sch, mikeneko-65-pcb.kicad_pcb, mikeneko-65-pcb.sch]
2022-07-06 プレートのガーバーファイルをplate直下に移動。
2022-12-03 ファームウェアを再ビルド、qmkのバージョンを明記
2022-12-03 プレートの厚みの指定を修正

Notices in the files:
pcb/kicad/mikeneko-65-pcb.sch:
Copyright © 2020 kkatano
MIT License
